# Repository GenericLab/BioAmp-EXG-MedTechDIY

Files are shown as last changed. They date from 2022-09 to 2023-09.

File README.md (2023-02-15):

Thanks a lot to the team at UpsideDown Labs!!!

## V1.0f - FeatherWing version, complete redesign for SMD 1206 parts

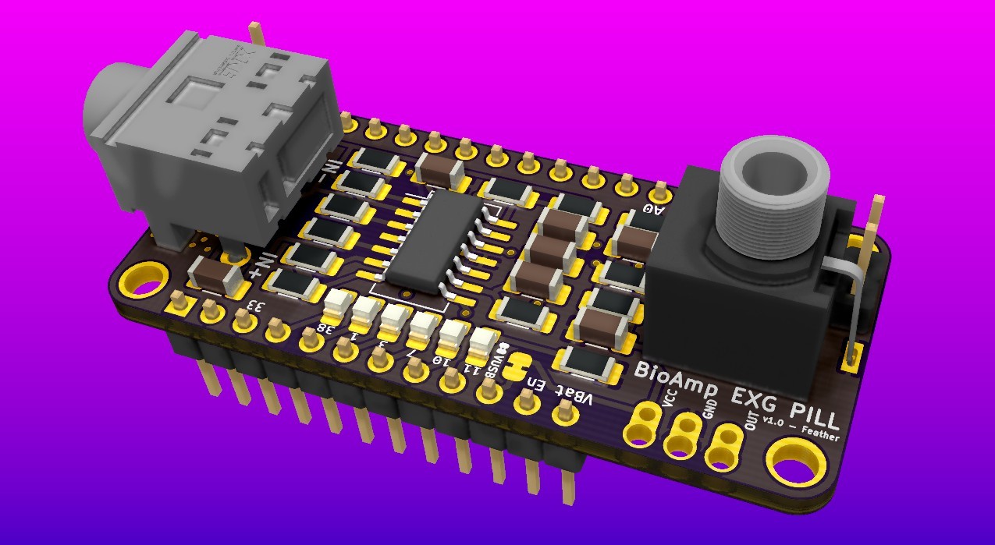
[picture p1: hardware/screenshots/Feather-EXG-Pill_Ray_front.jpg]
Total redesign for use with UM Feather S3


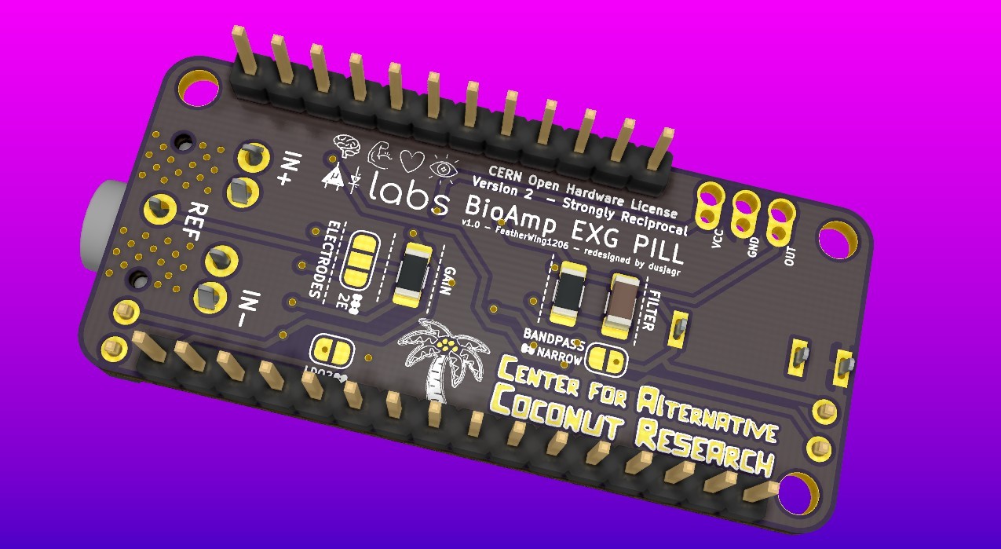
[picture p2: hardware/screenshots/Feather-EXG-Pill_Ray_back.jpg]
Total redesign for use with UM Feather S3


See more about the UM ESP-S3 board here: https://esp32s3.com/feathers3.html

## V1.0b - forked and ordered, in process of manufacturing

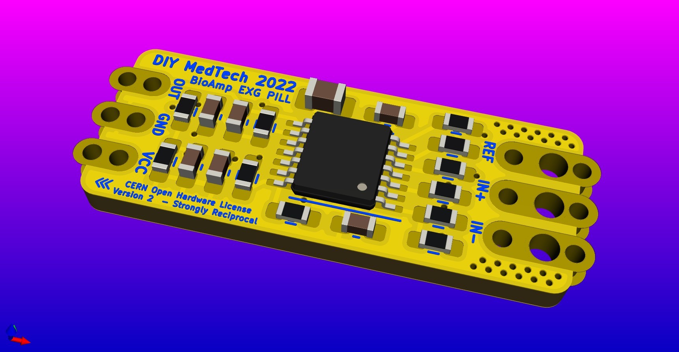
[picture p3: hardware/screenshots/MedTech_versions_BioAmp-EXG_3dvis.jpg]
Special MedTechDIY redesigned version 0.1


To be used in the future of our project week at HSLU: https://www.hackteria.org/wiki/Medizintechnik_DIY

Will be manufactured in GaudiLabs, still waiting for the parts... 0603 soooo small!!

Thanks a lot to the team at UpsideDown Labs!!!

# V1.0b - Original from Upside Down Labs

Down Labs BioAmp EXG Pill Crowd Supply banner (https://www.crowdsupply.com/upside-down-labs/bioamp-exg-pill)

     

BioAmp EXG Pill is a small (2.54 X 1.00 cm) and elegant Analog Front End (AFE) board for BioPotential signal acquisition that you can use with any 5v Micro Controller Unit (MCU) with an ADC. It is capable of recording publication grade BioPotential signals like ECG, EMG, EOG, and EEG without the inclusion of any dedicated Hardware/Software filter, see [BioAmp EXG Pill v0.7 intro video](https://www.youtube.com/watch?v=-G3z9fvQnuw) for more info. The v1.0 of BioAmp EXG pill provides even more flexibilty with configuration option for Gain, BandPass, Filter, and Electrodes.

Upside Down Labs BioAmp EXG Pill Assembled

| Connection |  Configuration |
| :---: | :---: |
| BioAmp EXG Pill - Connection  | BioAmp EXG Pill - Configuration|

| Basic Arduino Circuit |  Electromyography (EMG) |
| :---: | :---: |
| BioAmp EXG Pill - Basic Circuit  | BioAmp EXG Pill - Electromyography (EMG)|

| Electrooculography (EOG) Horizontal |  Electrooculography (EOG) Vertical |
| :---: | :---: |
| BioAmp EXG Pill - Electrooculography (EOG) Horizontal  | BioAmp EXG Pill - Electrooculography (EOG) Vertical|

| Electrocardiography (ECG) Lead 1 |  Electroencephalography (EEG) |
| :---: | :---: |
| BioAmp EXG Pill - Electrocardiography (ECG) Lead 1  | BioAmp EXG Pill - Electroencephalography (EEG)|

## Software
BioAmp EXG Pill works with any 5V microcontroller with an ADC like Arduino UNO/Nano or you can use dedicated 5v compatible ADC like ADS1115. To help with signal processing and cleaning you can use the included Arduino example sketches listed below.

| No. | Program| Description |
| ---- | ---- | ---- |
|1 | [FixedSampling](software/FixedSampling)| Sample from ADC at a fixed rate for easy processing of signal.|
|2 | [EMGFilter](software/EMGFilter)| A 74.5 - 149.5 Hz band pass filter sketch for clean Electromyography.|
|3 | [ECGFilter](software/ECGFilter)| A 0.5 - 44.5 Hz band-pass filter sketch for clean Electrocardiography.|
|4 | [EOGFilter](software/EOGFilter)| A 0.5 - 19.5 Hz band-pass filter sketch for clean Electrooculography.|
|5 | [EEGFilter](software/EEGFilter)| A 0.5 - 29.5 Hz band-pass filter sketch for clean Electroencephalography.|
|6 | [EMGEnvelop](software/EMGEnvelop)| EMG signal envelop detection for robotics and biomedical applications.|
|7 | [LEDBarGraph](software/LEDBarGraph)| LED bar graph showing EMG amplitude.|
|8 | [ServoControl](software/ServoControl)| Servo motor control with EMG.|
|9 | [HeartBeatDetection](software/HeartBeatDetection)| Standard deviation based heart beat detection algorithm.|
|10 | [EyeBlinkDetection](software/EyeBlinkDetection)|EOG based eye blink detection.|
|11 | [DrowsinessDetection](software/DrowsinessDetection)| Drowsiness detection using eye blink detection.|
|12 | [ClawController](software/ClawController)| Servo claw controller |
|13 | [EOGPhotoCaptureBLE](software/EOGPhotoCaptureBLE)| EOG based photo clicking machine using ESP32 BLE |

To-Do:

| No. | Program| Description |
| ---- | ---- | ---- |
|1 | HeartRate | Heart rate calculation with ECG.|
|2 | BrainWaves | Brain waves amplitude with FFT.|
|3 | EOGController | EOG based eye movement detection (left/right) to create a game controller.|

## Hardware

BioAmp EXG Pill has been created using KiCad and all the design files can be found under [hardware](hardware/) folder, including production [Gerber](hardware/gerbers) files. Images below shows a quick overview of the hardware design.

| PCB Front |  PCB Back |
| :---: | :---: |
| Upside Down Labs BioAmp EXG Pill front  | Upside Down Labs BioAmp EXG Pill back |

Upside Down Labs BioAmp EXG Pill front annotated

| Dimensions |  Schematic  |
| :---: | :---: |
| Upside Down Labs BioAmp EXG Pill dimensions  | Upside Down Labs BioAmp EXG Pill schematic |

## License

| Licenses Facts |  OSHWA Certification |
| :---: | :---: |
| <a href="LICENSE.md">Open Source Licenses Facts</a>  | <a href="https://certification.oshwa.org/in000026.html">Open Source Hardware Certification mark</a> |

#### Hardware
CERN Open Hardware License Version 2 - Strongly Reciprocal ([CERN-OHL-S-2.0](https://spdx.org/licenses/CERN-OHL-S-2.0.html)).

#### Software
MIT open source [license](http://opensource.org/licenses/MIT).

#### Documentation:
<br />This work is licensed under a <a rel="license" href="http://creativecommons.org/licenses/by/4.0/">Creative Commons Attribution 4.0 International License</a>.

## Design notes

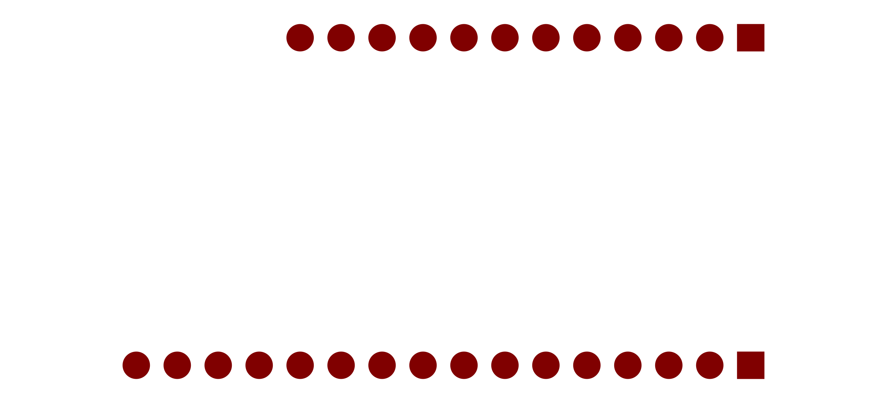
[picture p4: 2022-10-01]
hardware/svg2shenzhen/.svg2shenzhen-cache/images/B.Cu_g11140.png

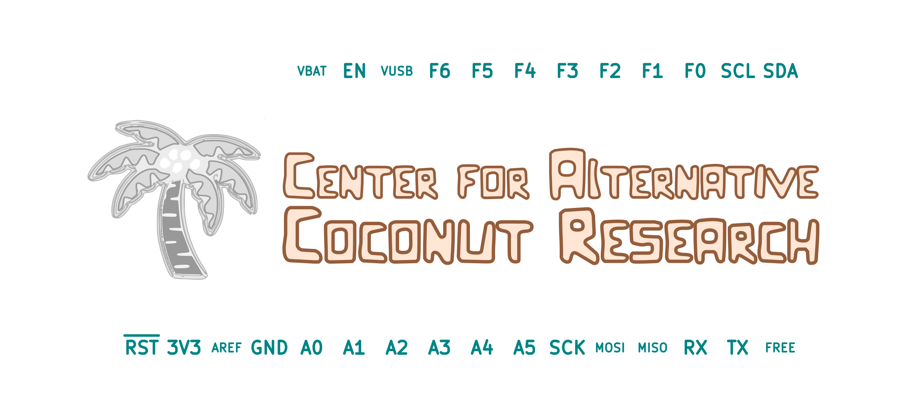
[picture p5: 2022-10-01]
hardware/svg2shenzhen/.svg2shenzhen-cache/images/F.SilkS_g11150.png

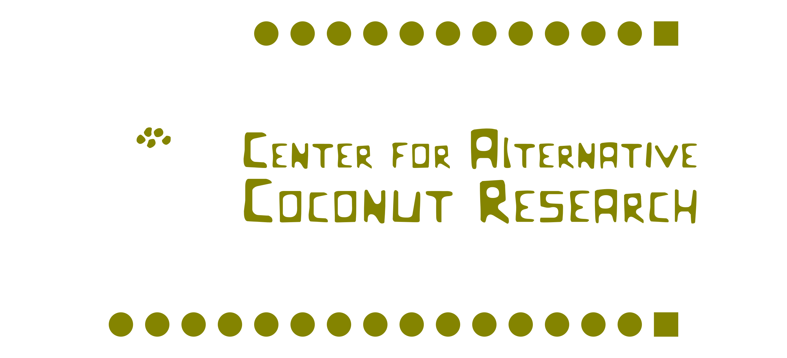
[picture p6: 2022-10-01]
hardware/svg2shenzhen/.svg2shenzhen-cache/images/F.Mask_g11148.png

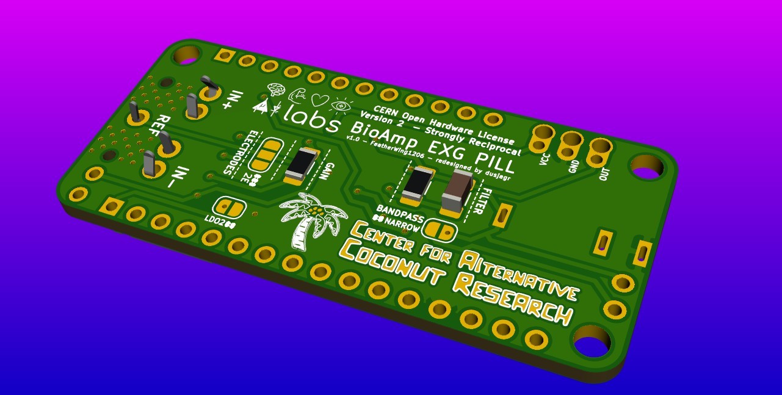
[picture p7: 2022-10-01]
hardware/screenshots/Feather-EXG-Pill_back.jpg

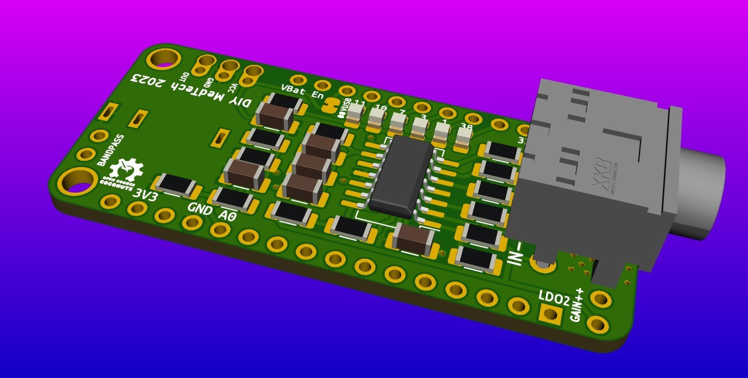
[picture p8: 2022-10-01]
hardware/screenshots/Feather-EXG-Pill_front.jpg

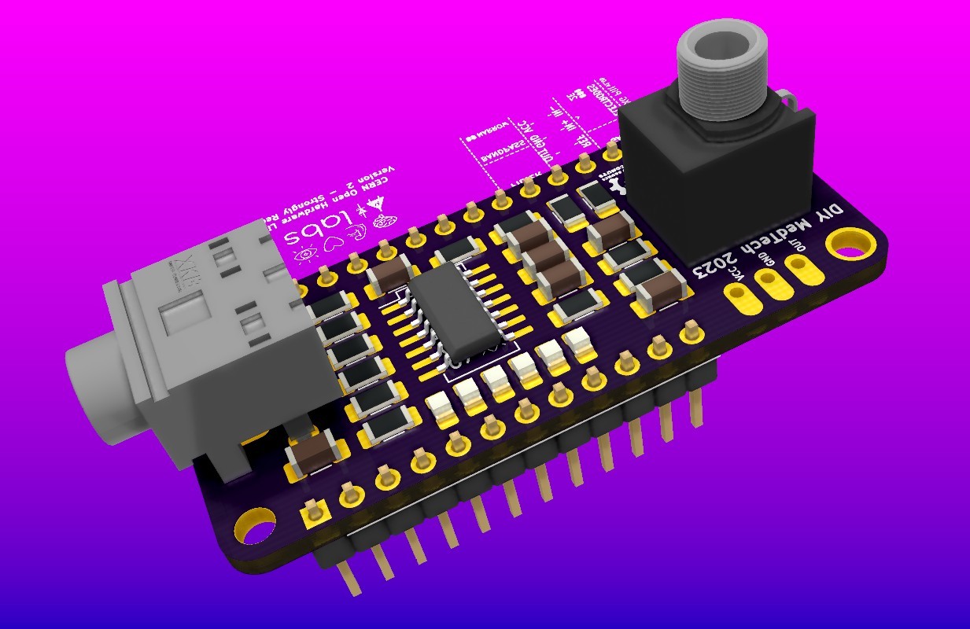
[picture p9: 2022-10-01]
hardware/screenshots/Feather-EXG-Pill.jpg

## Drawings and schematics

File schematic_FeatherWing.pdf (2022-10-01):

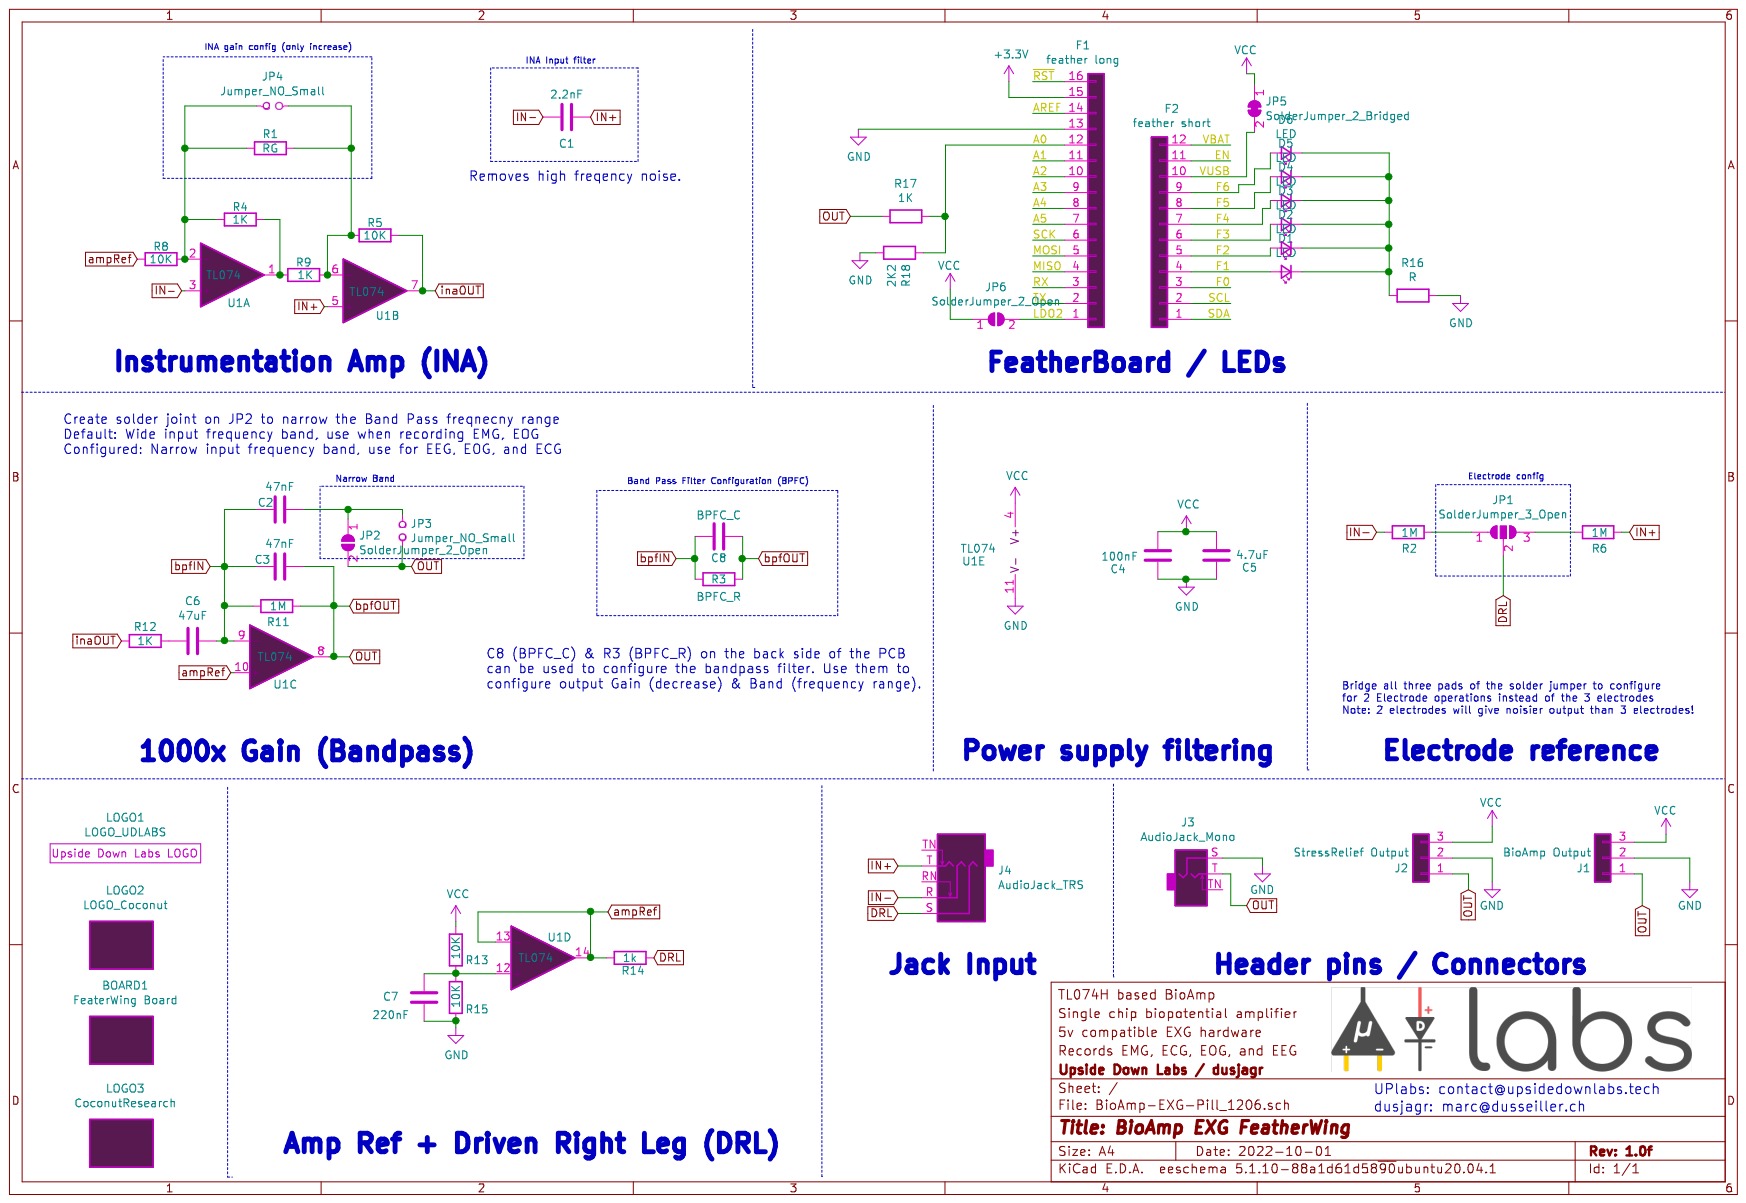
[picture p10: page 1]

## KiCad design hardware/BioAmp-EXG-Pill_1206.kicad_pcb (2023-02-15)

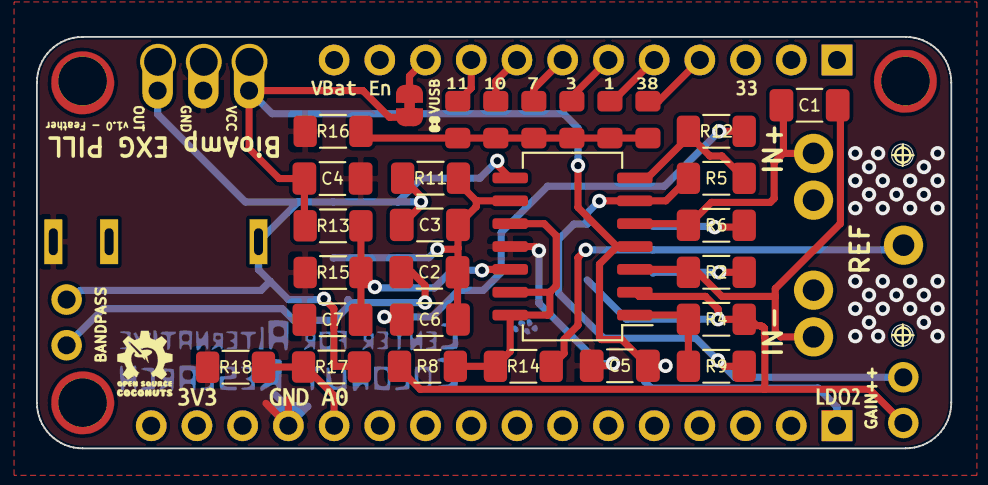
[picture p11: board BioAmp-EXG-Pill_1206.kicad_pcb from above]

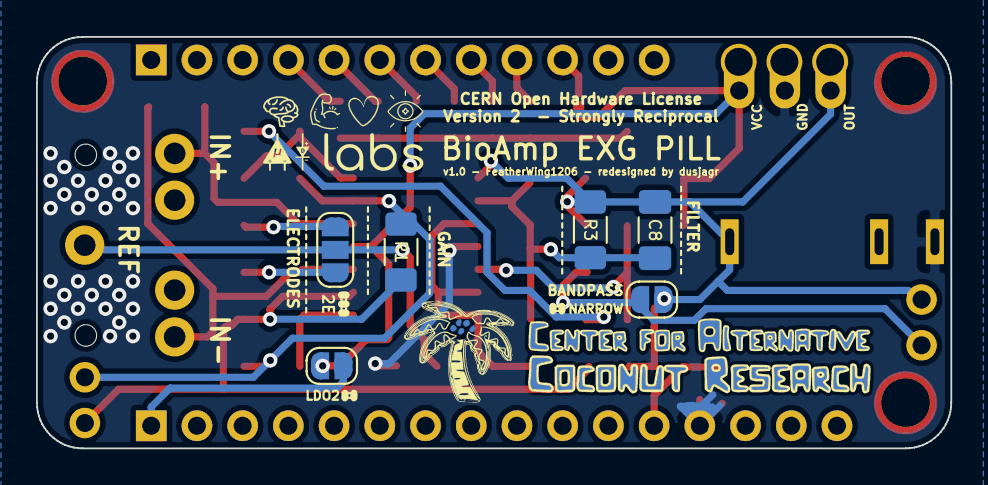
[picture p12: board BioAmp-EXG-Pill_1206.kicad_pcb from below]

Board: 2 copper layers, 50.8 x 22.9 mm, 47 parts (10 on the bottom side), 27 nets.

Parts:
BOARD1: FeaterWing Board; WeatherWing_empty
C1: 2.2nF; C_1206_dusjagr
C2, C3: 47nF; C_1206_dusjagr
C4: 100nF; C_1206_dusjagr
C5: 4.7uF; C_1206_dusjagr
C6: 47uF; C_1206_dusjagr
C7: 220nF; C_1206_dusjagr
C8: BPFC_C; C_1206_dusjagr
D1, D2, D3, D4, D5, D6: LED; LED_0805_2012Metric_Pad1.15x1.40mm_HandSolder
F1: feather long; PinHeader_1x16_FeatherLong
F2: feather short; PinHeader_1x12_FeatherShort
J1: BioAmp Output; BioAmp_PinHeader_1x03_P2.54mm_Vertical
J2: StressRelief Output; PinHeader_1x03_StressRelief
J3: AudioJack_Mono; PJ301M-12_dusjagr_3d
J4: AudioJack_TRS; AUDIO-Jack_3.5mm_5Pin
JP1: SolderJumper_3_Open; SolderJumper-3_P1.3mm_Open_RoundedPad1.0x1.5mm
JP2, JP6: SolderJumper_2_Open; SolderJumper-2_P1.3mm_Open_RoundedPad1.0x1.5mm
JP3, JP4: Jumper_NO_Small; PinHeader_1x02_P2.54mm_Vertical
JP5: SolderJumper_2_Bridged; SolderJumper-2_P1.3mm_Bridged
LOGO1: LOGO_UDLABS; LOGO-UpsideDownLabs-EXG
LOGO2: LOGO_Coconut; Coconut_logo
LOGO3: CoconutResearch; LOGO-CoconutText
R1: RG; R_1206_dusjagr
R2, R6, R11: 1M; R_1206_dusjagr
R3: BPFC_R; R_1206_dusjagr
R4, R9, R12, R17: 1K; R_1206_dusjagr
R5, R8, R13, R15: 10K; R_1206_dusjagr
R14: 1k; R_1206_dusjagr
R16: R; R_1206_dusjagr
R18: 2K2; R_1206_dusjagr
U1: TL074; SO-14_5.3x10.2mm_P1.27mm

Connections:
/A0: F1.12, R17.1, R18.1
/F1: D1.2, F2.4
/F2: D2.2, F2.5
/F3: D3.2, F2.6
/F4: D4.2, F2.7
/F5: D5.2, F2.8
/F6: D6.2, F2.9
/LDO2: F1.1, JP6.2
/VUSB: F2.10, JP5.2
DRL: J4.S, JP1.2, R14.1
GND: C4.1, C5.1, C7.2, F1.13, J1.2, J2.2, J3.S, R15.1, R16.1, R18.2, U1.11
IN+: C1.1, J4.T, R6.1, U1.5
IN-: C1.2, J4.R, R2.2, U1.3
unnamed: C2.1, JP2.1, JP3.1
unnamed: C6.2, R12.1
unnamed: C7.1, R13.1, R15.2, U1.12
unnamed: D1.1, D2.1, D3.1, D4.1, D5.1, D6.1, R16.2
unnamed: JP1.1, R2.1
unnamed: JP1.3, R6.2
unnamed: JP4.1, R1.2, R4.2, R8.1, U1.2
unnamed: JP4.2, R1.1, R5.2, R9.1, U1.6
unnamed: R4.1, R9.2, U1.1
OUT: C3.1, C8.1, J1.1, J2.1, J3.T, JP2.2, JP3.2, R3.1, R11.1, R17.2, U1.8
VCC: C4.2, C5.2, J1.3, J2.3, JP5.1, JP6.1, R13.2, U1.4
ampRef: R8.2, R14.2, U1.10, U1.13, U1.14
bpfIN: C2.2, C3.2, C6.1, C8.2, R3.2, R11.2, U1.9
inaOUT: R5.1, R12.2, U1.7

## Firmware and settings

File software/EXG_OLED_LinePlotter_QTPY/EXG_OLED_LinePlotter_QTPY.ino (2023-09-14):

// ECG Filter - BioAmp EXG Pill
// and some remaining code from EMG Envelop - BioAmp EXG Pill
// https://github.com/upsidedownlabs/BioAmp-EXG-Pill

// Upside Down Labs invests time and resources providing this open source code,
// please support Upside Down Labs and open-source hardware by purchasing
// products from Upside Down Labs!

// Copyright (c) 2021 Upside Down Labs - contact@upsidedownlabs.tech

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
/*
 *  Draws a scrolling graph of a single analog input (set to A0) on the OLED display
 *
 *  By Jon E. Froehlich
 *  @jonfroehlich
 *  http://makeabilitylab.io
 */

#define SAMPLE_RATE 75
#define DISPLAY_RATE 30
#define BAUD_RATE 115200
#define INPUT_PIN A2

const int buttonPin = 1;        // the number of the pushbutton pin
int buttonState = HIGH;          // the current reading from the input pin
int lastButtonState = HIGH;      // the previous reading from the input pin
int screenState = 1;             // different views on the OLED screen
unsigned long lastDebounceTime = 0;  // the last time the output pin was toggled
unsigned long debounceDelay = 50;    // the debounce time; increase if the output flickers
int reading;

//#define BUFFER_SIZE 128 // hope to increase this... only for EMG envelop

int MIN_ANALOG_INPUT = -2000;
int MAX_ANALOG_INPUT = 2000;

const int DELAY_LOOP_MS = 1; // change to slow down how often to read and graph value

//int circular_buffer[BUFFER_SIZE];
int data_index, sum;

#include <Wire.h>
#include <Adafruit_GFX.h>
#include <Adafruit_SSD1306.h>

#define SCREEN_WIDTH 128 // OLED display width, in pixels
#define SCREEN_HEIGHT 64 // OLED display height, in pixels

// Declaration for an SSD1306 display connected to I2C (SDA, SCL pins)
#define SDA_PIN 4
#define SCL_PIN 5
#define OLED_RESET -1 // Reset pin # (or -1 if sharing Arduino reset pin)
#define SCREEN_ADDRESS 0x3C ///< See datasheet for Address; 0x3D for 128x64, 0x3C for 128x32
Adafruit_SSD1306 _display(SCREEN_WIDTH, SCREEN_HEIGHT, &Wire, OLED_RESET);

int _circularBuffer[SCREEN_WIDTH]; //fast way to store values 
int _curWriteIndex = 0; // tracks where we are in the circular buffer

int displayUpdate;
int lastValue;
//float signal;

// for tracking fps
float _fps = 0;
unsigned long _frameCount = 0;
unsigned long _fpsStartTimeStamp = 0;

// status bar
boolean _drawStatusBar = false; // change to show/hide status bar
int _graphHeight = SCREEN_HEIGHT;

void setup() {
  analogReadResolution(12);
  pinMode(buttonPin, INPUT_PULLUP);
  Serial.begin(BAUD_RATE);

  // SSD1306_SWITCHCAPVCC = generate display voltage from 3.3V internally
  if (!_display.begin(SSD1306_SWITCHCAPVCC, 0x3C)) { // Address 0x3C for 128x64
    Serial.println(F("SSD1306 allocation failed"));
    for (;;); // Don't proceed, loop forever
  }

  // Clear the buffer
  _display.clearDisplay();
  _display.setRotation(2);
  _display.setTextSize(1);
  _display.setTextColor(WHITE, BLACK);
  _display.setCursor(0, 0);
  _display.println("Screen initialized!");
  _display.display();
  delay(500);
  _display.clearDisplay();

  showLogo_hackteria();
  delay(1000);

  if(_drawStatusBar){
    _graphHeight = SCREEN_HEIGHT - 16;
  }

  _fpsStartTimeStamp = millis();

  int displayUpdate = SAMPLE_RATE / DISPLAY_RATE;

}

void loop() {

  // Calculate elapsed time
	static unsigned long past = 0;
	unsigned long present = micros();
	unsigned long interval = present - past;
	past = present;

	// Run timer
	static long timer = 0;
	timer -= interval;
  // read Button

  reading = digitalRead(buttonPin);
    if (reading != lastButtonState) {
      // reset the debouncing timer
      lastDebounceTime = millis();
    }
     
    if ((millis() - lastDebounceTime) > debounceDelay) {
      if (reading != buttonState) {
        buttonState = reading;
        
        
  
        if (buttonState == HIGH) {
          screenState = !screenState;
          for (int i = 0; i < _display.width(); i++){
            _circularBuffer[i]=-10000;
          }
        }
      }
    }
  
  if (screenState == 0) {
          MIN_ANALOG_INPUT = -100;
          MAX_ANALOG_INPUT = 4095;
          _drawStatusBar = true;
          _graphHeight = SCREEN_HEIGHT-16;
          }
  if (screenState == 1) {
          MIN_ANALOG_INPUT = -1800;
          MAX_ANALOG_INPUT = 1000;
          _drawStatusBar = true;
          _graphHeight = SCREEN_HEIGHT-8;
  }
	// Sample and get envelop
	if(timer < 0) {
		timer += 1000000 / SAMPLE_RATE;
		float sensor_value = analogRead(INPUT_PIN);
    float signal = EOGFilter(sensor_value);
		if (screenState == 0) {
		lastValue = sensor_value;

    }
    if (screenState == 1) {
    lastValue = signal;
    int audioOut = map(signal,-2000,2000,0,1023);
    analogWrite(A0,audioOut);
    }


    if(displayUpdate <= 0) {
    if (screenState == 0) {
	  	_circularBuffer[_curWriteIndex++] = sensor_value;
    }
    if (screenState == 1) {
      _circularBuffer[_curWriteIndex++] = signal;
    }
      
      displayUpdate = SAMPLE_RATE / DISPLAY_RATE;
      updateDisplay();
      printValues(sensor_value,signal);
	  }
    else {
      displayUpdate--;
    }
    
  }
  lastButtonState = reading;
}

/**
 * update the display
 */
 void updateDisplay(){
  // Clear the display on each frame. We draw from the _circularBuffer
  _display.clearDisplay();
   // Set the circular buffer index back to zero when it reaches the 
  // right of the screen
  if(_curWriteIndex >= _display.width()){
    _curWriteIndex = 0;
  }
  
  if(_drawStatusBar){
    drawStatusBar(lastValue);
  }
  
  // Draw the line graph based on data in _circularBuffer
  int xPos = 0; 
  for (int i = _curWriteIndex; i < _display.width(); i++){
    int envelop = _circularBuffer[i];
    int envelop_last = _circularBuffer[i-1];    
     drawLine(xPos, envelop, envelop_last);
     xPos++;
  }
  
  for(int i = 1; i < _curWriteIndex; i++){
    int envelop = _circularBuffer[i];
    int envelop_last = _circularBuffer[i-1]; 
    drawLine(xPos, envelop, envelop_last);
    xPos++;;
  }
  
  _display.display();
  calcFrameRate();
  delay(DELAY_LOOP_MS);
 }

/**
 * Draw the line at the given x position and analog value
 */
void drawLine(int xPos, int envelop, int envelop_last){
  int lineHeight = map(envelop, MIN_ANALOG_INPUT, MAX_ANALOG_INPUT, 0, _graphHeight);
  int lineBottom = map(envelop_last, MIN_ANALOG_INPUT, MAX_ANALOG_INPUT, 0, _graphHeight);
  int yPos = _display.height() - lineHeight;
  if (screenState == 0) {
  _display.drawFastVLine(xPos, yPos-16, abs(lineBottom-lineHeight+1), SSD1306_WHITE);
  }
  if (screenState == 1) {
  _display.drawFastVLine(xPos, yPos, abs(lineBottom-lineHeight+1), SSD1306_WHITE);
  }
}

void printValues(int value1, int value2) {
 //   Serial.print(reading);
//		Serial.print("\t");
  //  Serial.print(screenState);
//		Serial.print("\t");
 //   Serial.print(value1);
//		Serial.print("\t");
		Serial.println(value2);
}

/**
 * Call this every frame to calculate frame rate
 */
void calcFrameRate() {
    
  unsigned long elapsedTime = millis() - _fpsStartTimeStamp;
  _frameCount++;
  if (elapsedTime > 1000) {
    _fps = _frameCount / (elapsedTime / 1000.0);
    _fpsStartTimeStamp = millis();
    _frameCount = 0;
  }
}

/**
 * Draws the status bar at top of screen with fps and analog value
 */
void drawStatusBar(int displayVal) {

   // erase status bar by drawing all black
  _display.fillRect(0, 0, _display.width(), 16, SSD1306_BLACK); 
  
  // Draw frame count
  int16_t x1, y1;
  uint16_t w, h;

  if (screenState == 0) {
  _display.setTextSize(1);
  _display.getTextBounds("XX.XX fps", 0, 0, &x1, &y1, &w, &h);
  _display.setCursor(_display.width() - w, 56);
  _display.print(_fps);
  _display.print(" fps");
    // Draw current val
  _display.setTextSize(2);
  _display.setCursor(0, 48);
  _display.print(displayVal);
    _display.setTextSize(1);
    _display.getTextBounds("XX ANALOG", 0, 0, &x1, &y1, &w, &h);
    _display.setCursor(_display.width() - w, 48);
    _display.print("A");
    _display.print(INPUT_PIN);
    _display.print(" ANALOG");
  }
  if (screenState == 1) {
    _display.setTextSize(1);
    _display.getTextBounds("XX EOG-FILTERED", 0, 0, &x1, &y1, &w, &h);
    _display.setCursor(_display.width() - w, 0);
    _display.print("A");
    _display.print(INPUT_PIN);
    _display.print(" EOG-FILTERED");
  }
}

/* Envelop detection algorithm
int getEnvelop(int abs_emg){
	sum -= circular_buffer[data_index];
	sum += abs_emg;
	circular_buffer[data_index] = abs_emg;
	data_index = (data_index + 1) % BUFFER_SIZE;
	return (sum/BUFFER_SIZE) * 2;
}
*/

// Band-Pass Butterworth IIR digital filter, generated using filter_gen.py.
// Sampling rate: 500.0 Hz, frequency: [74.5, 149.5] Hz.
// Filter is order 4, implemented as second-order sections (biquads).
// Reference: 
// https://docs.scipy.org/doc/scipy/reference/generated/scipy.signal.butter.html
// https://courses.ideate.cmu.edu/16-223/f2020/Arduino/FilterDemos/filter_gen.py
float EMGFilter(float input)
{
  float output = input;
  {
    static float z1, z2; // filter section state
    float x = output - 0.05159732*z1 - 0.36347401*z2;
    output = 0.01856301*x + 0.03712602*z1 + 0.01856301*z2;
    z2 = z1;
    z1 = x;
  }
  {
    static float z1, z2; // filter section state
    float x = output - -0.53945795*z1 - 0.39764934*z2;
    output = 1.00000000*x + -2.00000000*z1 + 1.00000000*z2;
    z2 = z1;
    z1 = x;
  }
  {
    static float z1, z2; // filter section state
    float x = output - 0.47319594*z1 - 0.70744137*z2;
    output = 1.00000000*x + 2.00000000*z1 + 1.00000000*z2;
    z2 = z1;
    z1 = x;
  }
  {
    static float z1, z2; // filter section state
    float x = output - -1.00211112*z1 - 0.74520226*z2;
    output = 1.00000000*x + -2.00000000*z1 + 1.00000000*z2;
    z2 = z1;
    z1 = x;
  }
  return output;
}

// Band-Pass Butterworth IIR digital filter, generated using filter_gen.py.
// Sampling rate: 125.0 Hz, frequency: [0.5, 44.5] Hz.
// Filter is order 4, implemented as second-order sections (biquads).
// Reference:
// https://docs.scipy.org/doc/scipy/reference/generated/scipy.signal.butter.html
// https://courses.ideate.cmu.edu/16-223/f2020/Arduino/FilterDemos/filter_gen.py
float ECGFilter(float input)
{
  float output = input;
  {
    static float z1, z2; // filter section state
    float x = output - 0.70682283*z1 - 0.15621030*z2;
    output = 0.28064917*x + 0.56129834*z1 + 0.28064917*z2;
    z2 = z1;
    z1 = x;
  }
  {
    static float z1, z2; // filter section state
    float x = output - 0.95028224*z1 - 0.54073140*z2;
    output = 1.00000000*x + 2.00000000*z1 + 1.00000000*z2;
    z2 = z1;
    z1 = x;
  }
  {
    static float z1, z2; // filter section state
    float x = output - -1.95360385*z1 - 0.95423412*z2;
    output = 1.00000000*x + -2.00000000*z1 + 1.00000000*z2;
    z2 = z1;
    z1 = x;
  }
  {
    static float z1, z2; // filter section state
    float x = output - -1.98048558*z1 - 0.98111344*z2;
    output = 1.00000000*x + -2.00000000*z1 + 1.00000000*z2;
    z2 = z1;
    z1 = x;
  }
  return output;
}

// Band-Pass Butterworth IIR digital filter, generated using filter_gen.py.
// Sampling rate: 75.0 Hz, frequency: [0.5, 19.5] Hz.
// Filter is order 4, implemented as second-order sections (biquads).
// Reference: 
// https://docs.scipy.org/doc/scipy/reference/generated/scipy.signal.butter.html
// https://courses.ideate.cmu.edu/16-223/f2020/Arduino/FilterDemos/filter_gen.py
float EOGFilter(float input)
{
  float output = input;
  {
    static float z1, z2; // filter section state
    float x = output - 0.02977423*z1 - 0.04296318*z2;
    output = 0.09797471*x + 0.19594942*z1 + 0.09797471*z2;
    z2 = z1;
    z1 = x;
  }
  {
    static float z1, z2; // filter section state
    float x = output - 0.08383952*z1 - 0.46067709*z2;
    output = 1.00000000*x + 2.00000000*z1 + 1.00000000*z2;
    z2 = z1;
    z1 = x;
  }
  {
    static float z1, z2; // filter section state
    float x = output - -1.92167271*z1 - 0.92347975*z2;
    output = 1.00000000*x + -2.00000000*z1 + 1.00000000*z2;
    z2 = z1;
    z1 = x;
  }
  {
    static float z1, z2; // filter section state
    float x = output - -1.96758891*z1 - 0.96933514*z2;
    output = 1.00000000*x + -2.00000000*z1 + 1.00000000*z2;
    z2 = z1;
    z1 = x;
  }
  return output;
}

const unsigned char hackteria_logo [] PROGMEM = {
  // 'hackteria_logo, 128x64px
  0x00, 0x00, 0x00, 0x00, 0x00, 0x00, 0x00, 0x00, 0x00, 0x00, 0x00, 0x00, 0x00, 0x00, 0x00, 0x00, 
  0x00, 0x00, 0x00, 0x00, 0x00, 0x00, 0x00, 0x00, 0x00, 0x00, 0x00, 0x00, 0x00, 0x00, 0x00, 0x00,
  0x00, 0x00, 0x00, 0x00, 0x00, 0x00, 0x00, 0x00, 0x00, 0x00, 0x00, 0x00, 0x00, 0x00, 0x00, 0x00, 
  0x00, 0x00, 0x00, 0x00, 0x00, 0x00, 0x00, 0x00, 0x00, 0x00, 0x00, 0x00, 0x00, 0x00, 0x00, 0x00, 
  0x00, 0x00, 0x00, 0x00, 0x00, 0x00, 0x00, 0x00, 0x00, 0x00, 0x00, 0x00, 0x00, 0x00, 0x00, 0x00, 
  0x00, 0x00, 0x00, 0x00, 0x00, 0x00, 0x00, 0x00, 0x00, 0x00, 0x00, 0x00, 0x00, 0x00, 0x00, 0x00, 
  0x00, 0x00, 0x00, 0x00, 0x00, 0x00, 0x00, 0x00, 0x00, 0x00, 0x00, 0x00, 0x00, 0x00, 0x00, 0x00, 
  0x00, 0x00, 0x00, 0x00, 0x00, 0x00, 0x00, 0x00, 0x00, 0x00, 0x00, 0x00, 0x00, 0x00, 0x00, 0x00, 
  0x00, 0x00, 0x00, 0x00, 0x00, 0x00, 0x00, 0x00, 0x00, 0x00, 0x00, 0x00, 0x00, 0x00, 0x00, 0x00, 
  0x00, 0x00, 0x00, 0x00, 0x00, 0x00, 0x00, 0x00, 0x00, 0x00, 0x00, 0x00, 0x00, 0x00, 0x00, 0x00, 
  0x00, 0x00, 0x00, 0x00, 0x00, 0x00, 0x00, 0x00, 0x00, 0x00, 0x00, 0x00, 0x00, 0x00, 0x00, 0x00, 
  0x00, 0x00, 0x00, 0x00, 0x00, 0x00, 0x00, 0x00, 0x00, 0x00, 0x00, 0x00, 0x00, 0x00, 0x00, 0x00, 
  0x00, 0x00, 0x00, 0x00, 0x00, 0x00, 0x00, 0x00, 0x00, 0x00, 0x00, 0x00, 0x00, 0x00, 0x00, 0x00, 
  0x00, 0x00, 0x00, 0x00, 0x00, 0x00, 0x00, 0x00, 0x00, 0x00, 0x00, 0x00, 0x00, 0x00, 0x00, 0x00, 
  0x00, 0x00, 0x00, 0x00, 0x00, 0x00, 0x00, 0x00, 0x00, 0x00, 0x00, 0x00, 0x00, 0x00, 0x00, 0x00, 
  0x00, 0x00, 0x00, 0x00, 0x00, 0x00, 0x00, 0x00, 0x00, 0x00, 0x00, 0x00, 0x00, 0x00, 0x00, 0x00, 
  0x00, 0x00, 0x00, 0x00, 0x00, 0x00, 0x00, 0x00, 0x00, 0x00, 0x00, 0x00, 0x00, 0x00, 0x00, 0x00, 
  0x00, 0x00, 0x00, 0x00, 0x00, 0x00, 0x00, 0x00, 0x00, 0x00, 0x00, 0x00, 0x00, 0x00, 0x00, 0x00, 
  0x00, 0x00, 0x00, 0x00, 0x00, 0x00, 0x00, 0x3f, 0x00, 0x00, 0x00, 0x00, 0x00, 0x00, 0x00, 0x00, 
  0x00, 0x00, 0x00, 0x00, 0x00, 0x00, 0x01, 0xff, 0x00, 0x00, 0x00, 0x00, 0x00, 0x00, 0x00, 0x00, 
  0x00, 0x00, 0x00, 0x00, 0x00, 0x00, 0x07, 0xf8, 0x00, 0x00, 0x00, 0x00, 0x00, 0x00, 0x00, 0x00, 
  0x00, 0x00, 0x00, 0x00, 0x00, 0x00, 0x1f, 0x80, 0x00, 0x00, 0x00, 0x00, 0x00, 0x00, 0x00, 0x00, 
  0x00, 0x00, 0x00, 0x00, 0x00, 0x00, 0x3c, 0x3f, 0xf8, 0x00, 0x00, 0x00, 0x00, 0x00, 0x00, 0x00, 
  0x00, 0x00, 0x00, 0x00, 0x00, 0x00, 0xf9, 0xff, 0xff, 0x00, 0x00, 0x00, 0x00, 0x00, 0x00, 0x00, 
  0x00, 0x00, 0x00, 0x00, 0x00, 0x01, 0xe1, 0xe0, 0x0f, 0xc0, 0x00, 0x00, 0x00, 0x00, 0x00, 0x00, 
  0x00, 0x00, 0x00, 0x00, 0x00, 0x03, 0xc0, 0x00, 0x01, 0xe0, 0x00, 0x00, 0x00, 0x00, 0x00, 0x00, 
  0x00, 0x00, 0x00, 0x00, 0x00, 0x07, 0x80, 0x00, 0x00, 0x70, 0x00, 0x00, 0x00, 0x00, 0x00, 0x00, 
  0x00, 0x00, 0x00, 0x00, 0x00, 0x07, 0x00, 0x00, 0x00, 0x38, 0x00, 0x00, 0x00, 0x00, 0x00, 0x00, 
  0x00, 0x00, 0x00, 0x00, 0x00, 0x0e, 0x30, 0x70, 0x00, 0x1c, 0x00, 0x00, 0x00, 0x00, 0x00, 0x00, 
  0x00, 0x00, 0x00, 0x00, 0x00, 0x0c, 0x2f, 0xff, 0xc0, 0x0e, 0x00, 0x00, 0x00, 0x00, 0x00, 0x00, 
  0x00, 0x00, 0x00, 0x00, 0x00, 0x1c, 0x1f, 0xff, 0xf1, 0x87, 0x00, 0x00, 0x00, 0x00, 0x00, 0x00, 
  0x00, 0x00, 0x00, 0x00, 0x00, 0x18, 0x3c, 0x3c, 0x7e, 0x03, 0x00, 0x00, 0x00, 0x00, 0x00, 0x00, 
  0x00, 0x00, 0x00, 0x00, 0x00, 0x38, 0x73, 0x68, 0xfe, 0x03, 0x00, 0x00, 0x00, 0x00, 0x00, 0x00, 
  0x00, 0x00, 0x00, 0x00, 0x00, 0x30, 0x87, 0x80, 0xff, 0x00, 0x00, 0x00, 0x00, 0x00, 0x00, 0x00, 
  0x00, 0x00, 0x00, 0x00, 0x00, 0x71, 0x8f, 0x8c, 0x3f, 0x80, 0x00, 0x00, 0x00, 0x00, 0x00, 0x00, 
  0x00, 0x00, 0x00, 0x00, 0x00, 0x71, 0x8f, 0x89, 0x01, 0xc0, 0x00, 0x00, 0x00, 0x00, 0x00, 0x00, 
  0x00, 0x00, 0x00, 0x00, 0x00, 0x70, 0xaf, 0x8f, 0x01, 0xe0, 0x00, 0x00, 0x00, 0x00, 0x00, 0x00, 
  0x00, 0x00, 0x00, 0x00, 0x00, 0x70, 0x7f, 0x0e, 0x39, 0x60, 0x00, 0x00, 0x00, 0x00, 0x00, 0x00, 
  0x00, 0x00, 0x00, 0x00, 0x00, 0x60, 0x3f, 0x0f, 0x7c, 0x70, 0x00, 0x00, 0x00, 0x00, 0x00, 0x00, 
  0x00, 0x00, 0x00, 0x00, 0x00, 0x60, 0x18, 0x0e, 0x7c, 0xf0, 0x00, 0x00, 0x00, 0x00, 0x00, 0x00, 
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
};

void showLogo_hackteria(){
  _display.clearDisplay(); // Make sure the display is cleared
  _display.drawBitmap(0, -17, hackteria_logo, 128, 64, WHITE);  
  _display.setTextSize(2);
  _display.setTextColor(WHITE);
  _display.setCursor(11,49);
  _display.println("HACKTERIA");
  // Update the display
  _display.display();
  delay(30);
}

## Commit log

2022-09-15 redesigned PCB for manufacture MedTech style
    [BioAmp-EXG-Pill-BOM.ods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]
2022-10-01 complete redesign for FeatherWint
    [BioAmp-EXG-Pill-BOM.ods, BioAmp-EXG-Pill_1206.kicad_pcb, BioAmp-EXG-Pill_1206.sch]
2023-02-15 new bom and new ESP32 code
    [BioAmp-EXG-Pill-B_Cu.gbr, BioAmp-EXG-Pill-B_Mask.gbr, BioAmp-EXG-Pill-B_SilkS.gbr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]
